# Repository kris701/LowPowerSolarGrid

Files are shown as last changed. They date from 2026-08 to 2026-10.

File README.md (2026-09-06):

# Low Power Solar Grid
A project to make a low power solar setup with a hybrid switcher
The general idea is that most small scale solar chargers and controllers you can buy, takes a lot of base load power.
Say, if you have 300W of solar capacity, its a bit wasteful for the charge controller to be constantly eating 5-10W all day long.

So the general idea is to make a very low power setup that can work with little to no base load.

For this, there are 2 main components, the Low Power Solar Charger and the Low Power Power Switch.
The Charger part adds an extra controller before the charge controller step, which has a Arduino in a low power setup that switches power on and off the 
controller depending on how much light comes in from a light sensor outside. The switches are bistatic relay, so they effectively dont use any base load.
The controller itself uses less than a watt (i cant measure any lower).

The Power Switch part is to have a continuous supply of 12V power to the systems that use it.
It measures the voltage on the battery, and when the voltage is sufficiently high, draws power from the battery. If its too low, it instead draws power
from a 230V to 12V charger.

lpsolargrid



Everything in the 12V range is connected by Anderson connectors to make a unified connector for everything.

Keep in mind that this is a low power setup, so dont expect to draw more than 200-300W from this setup.

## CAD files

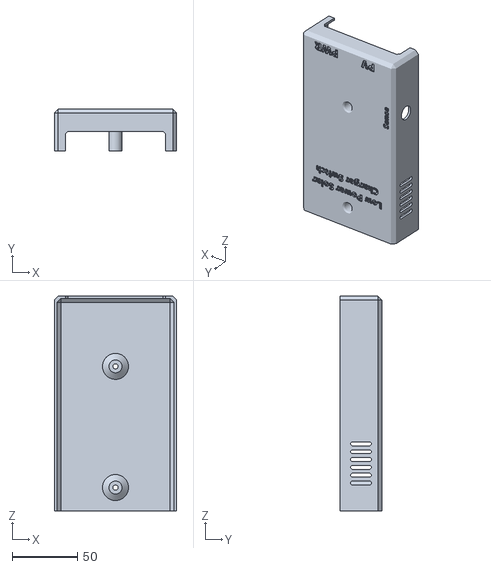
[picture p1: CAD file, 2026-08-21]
3D Prints/SolarSwitch_Cover.stl
94.0 x 32.0 x 165.0

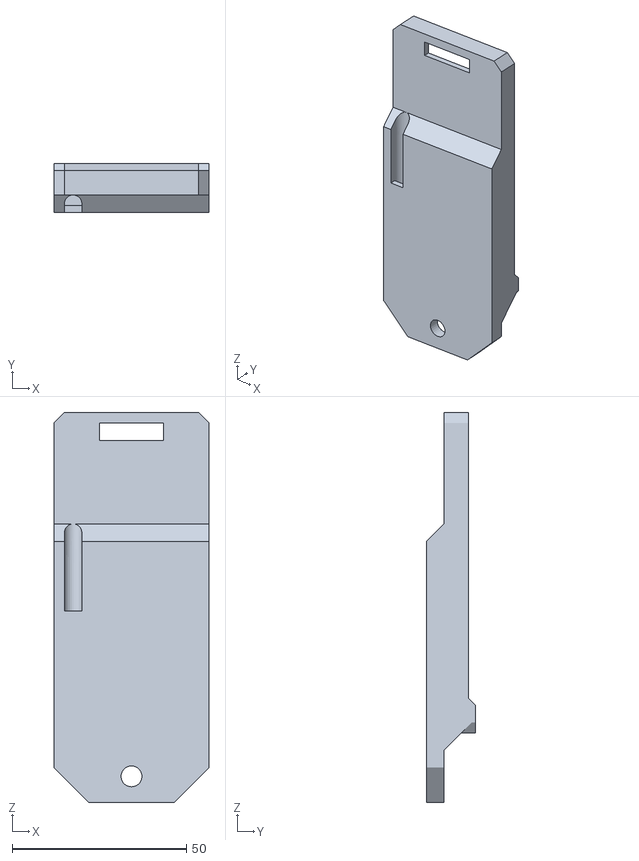
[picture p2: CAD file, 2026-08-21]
3D Prints/SolarSensor_Mount.stl
44.5 x 14.0 x 112.0

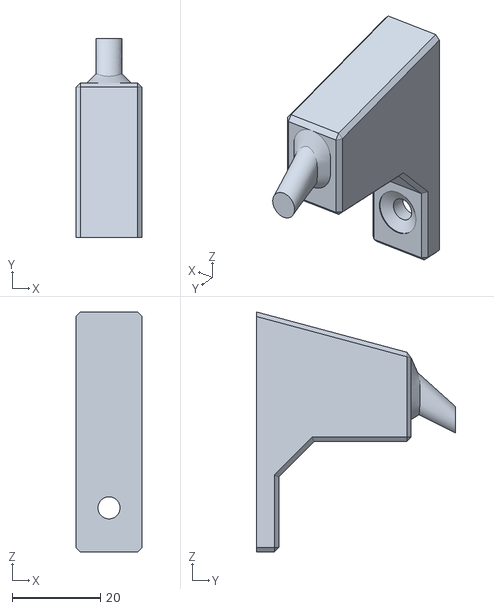
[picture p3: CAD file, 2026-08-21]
3D Prints/SolarPanel_Mount.stl
15.0 x 45.0 x 54.4

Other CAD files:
3D Prints/SolarPanel_Mount.f3d
3D Prints/SolarSensor_Mount.f3d
3D Prints/SolarSwitch_Cover.f3d

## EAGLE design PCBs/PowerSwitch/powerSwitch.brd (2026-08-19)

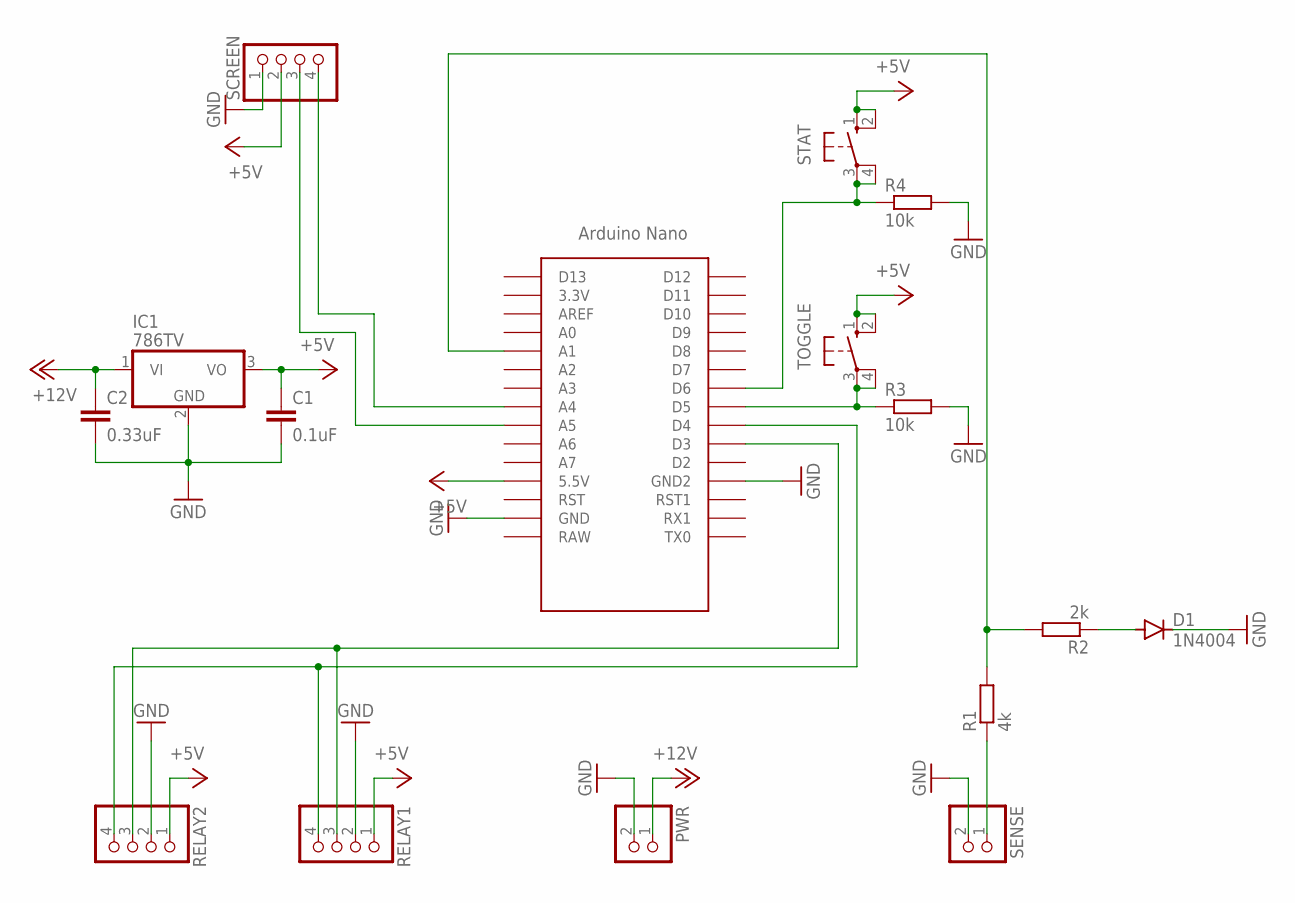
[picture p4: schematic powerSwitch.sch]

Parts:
C1: 0.1uF; C5B2.5
C2: 0.33uF; C5B2.5
D1: 1N4004; DO41-10
IC1: 786TV; TO220V
NANO: NANO
PWR: PINHD-1X2; 1X02
R1: 4k; 0204/7
R2: 2k; 0204/7
R3, R4: 10k; 0204/7
RELAY1, RELAY2: PINHD-1X4; 1X04
SCREEN: PINHD-1X4; 1X04
SENSE: PINHD-1X2; 1X02
STAT: 10-XX; B3F-10XX
TOGGLE: 10-XX; B3F-10XX

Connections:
+5V: C1.1, IC1.3 (VO), NANO.5V (5.5V), RELAY1.1, RELAY2.1, SCREEN.2, STAT.1 (S), STAT.2 (S1), TOGGLE.1 (S), TOGGLE.2 (S1)
+12V: C2.1, IC1.1 (VI), PWR.1
GND: C1.2, C2.2, D1.C, IC1.2 (GND), NANO.GND, NANO.GND1 (GND2), PWR.2, R3.2, R4.2, RELAY1.2, RELAY2.2, SCREEN.1, SENSE.2
unnamed: NANO.D3, RELAY1.3, RELAY2.3
unnamed: NANO.D4, RELAY1.4, RELAY2.4
unnamed: R1.1, SENSE.1
unnamed: NANO.A1, R1.2, R2.2
unnamed: D1.A, R2.1
unnamed: NANO.D5, R3.1, TOGGLE.3, TOGGLE.4 (P1)
unnamed: NANO.D6, R4.1, STAT.3, STAT.4 (P1)
unnamed: NANO.A5, SCREEN.3
unnamed: NANO.A4, SCREEN.4

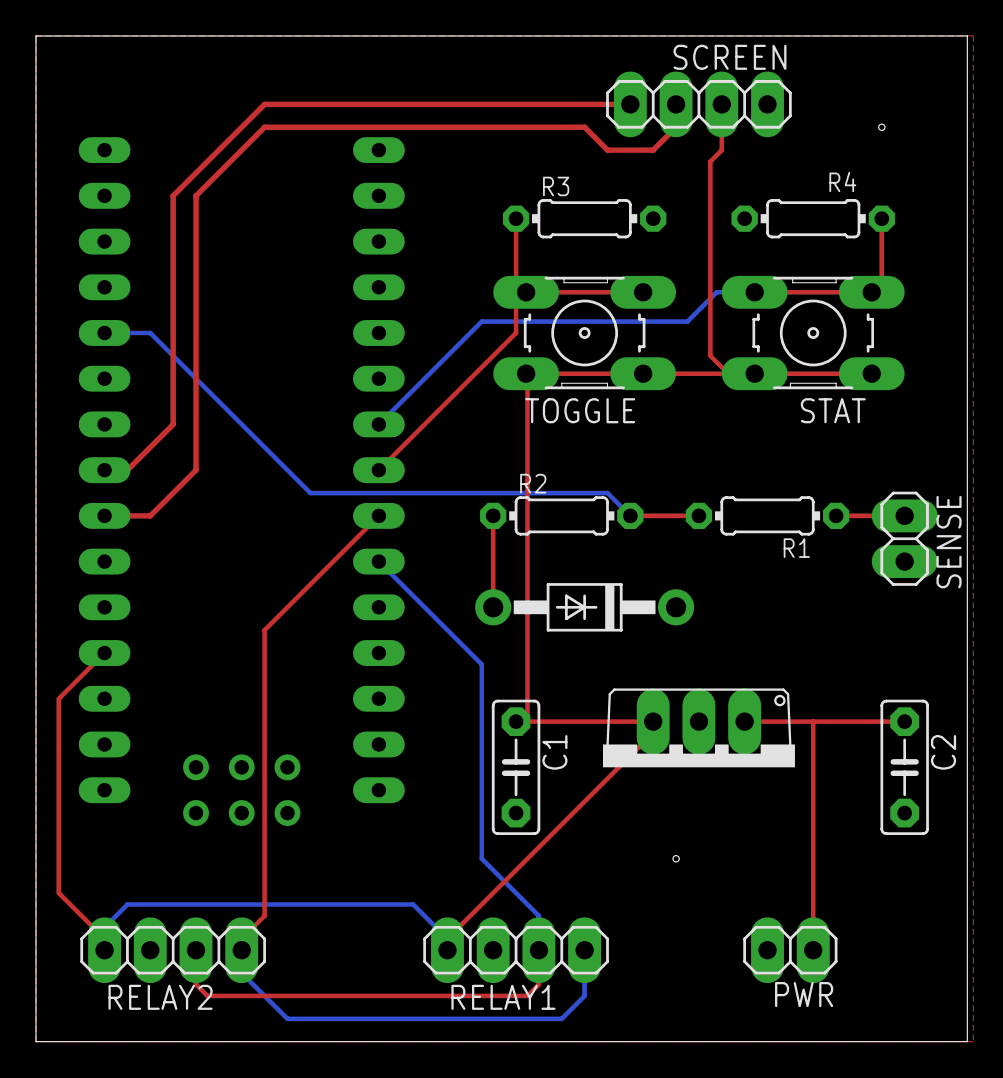
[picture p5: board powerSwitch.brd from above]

Board: 2 copper layers, 51.7 x 55.9 mm, 16 parts (0 on the bottom side), 12 nets.

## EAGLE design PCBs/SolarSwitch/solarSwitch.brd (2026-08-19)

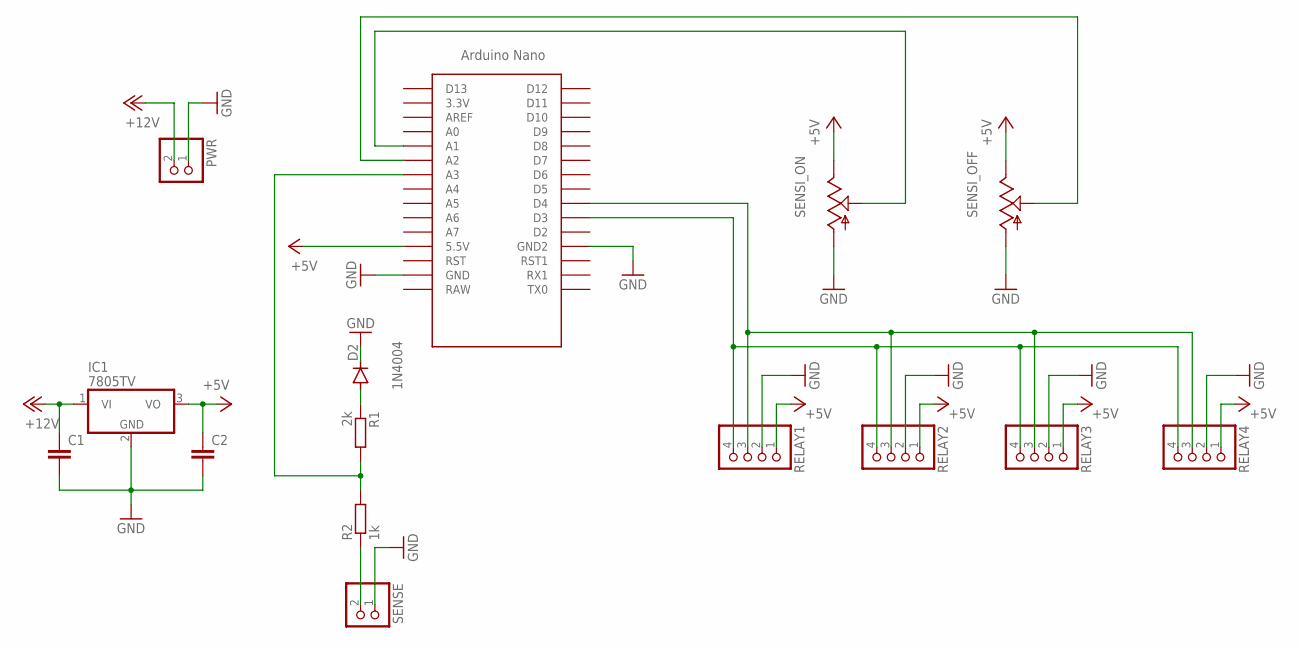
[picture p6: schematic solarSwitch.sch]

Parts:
C1, C2: C5/3; C5B3
D2: 1N4004; DO41-10
IC1: 7805TV; TO220V
PWR: PINHD-1X2; 1X02
R1: 2k; 0204/7
R2: 1k; 0204/7
RELAY1, RELAY2, RELAY3, RELAY4: PINHD-1X4; 1X04
SENSE: PINHD-1X2; 1X02
SENSI_OFF: TRIM_US-B25P; B25P
SENSI_ON: TRIM_US-B25P; B25P
U$1: NANO

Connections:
+5V: C2.1, IC1.3 (VO), RELAY1.1, RELAY2.1, RELAY3.1, RELAY4.1, SENSI_OFF.E, SENSI_ON.E, U$1.5V (5.5V)
+12V: C1.1, IC1.1 (VI), PWR.2
GND: C1.2, C2.2, D2.C, IC1.2 (GND), PWR.1, RELAY1.2, RELAY2.2, RELAY3.2, RELAY4.2, SENSE.1, SENSI_OFF.A, SENSI_ON.A, U$1.GND, U$1.GND1 (GND2)
unnamed: SENSI_ON.S, U$1.A1
unnamed: R2.1, SENSE.2
unnamed: D2.A, R1.1
unnamed: SENSI_OFF.S, U$1.A2
unnamed: RELAY1.3, RELAY2.3, RELAY3.3, RELAY4.3, U$1.D4
unnamed: R1.2, R2.2, U$1.A3
unnamed: RELAY1.4, RELAY2.4, RELAY3.4, RELAY4.4, U$1.D3

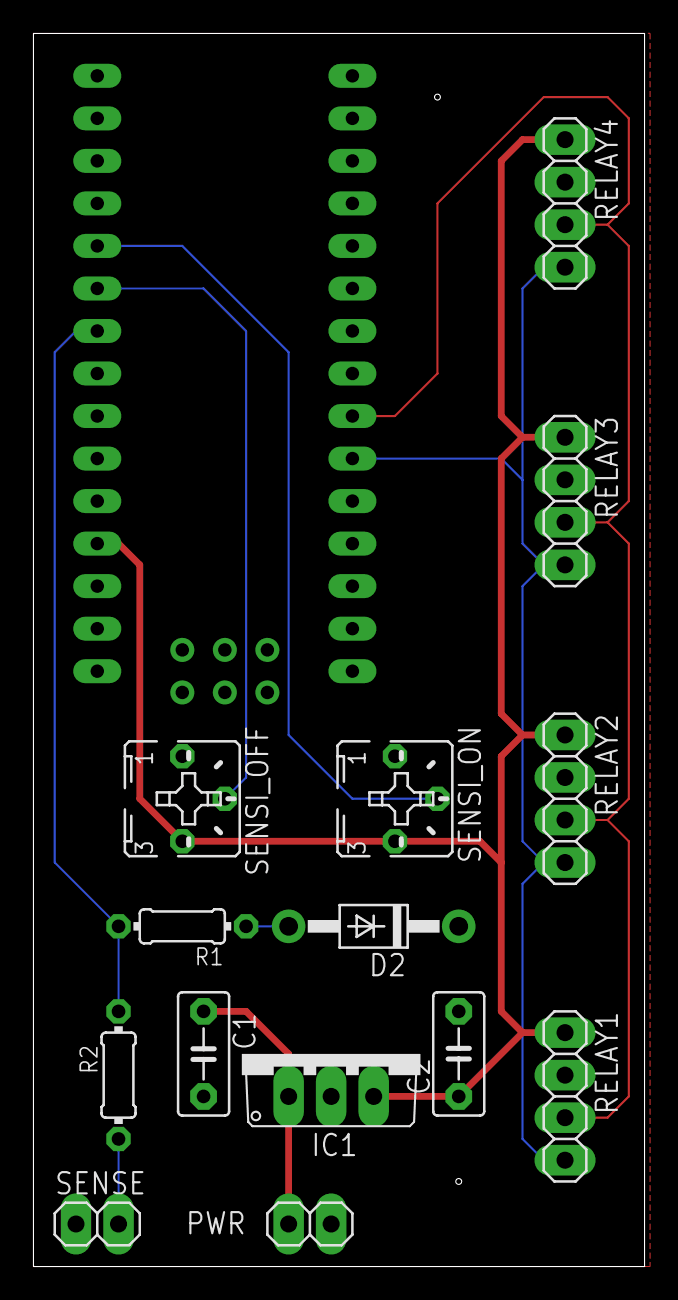
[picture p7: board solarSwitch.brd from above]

Board: 2 copper layers, 36.5 x 73.7 mm, 15 parts (0 on the bottom side), 10 nets.

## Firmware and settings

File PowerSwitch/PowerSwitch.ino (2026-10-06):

#include <EEPROM.h>
#include <SPI.h>
#include <Wire.h>
#include <Adafruit_GFX.h>
#include <Adafruit_SSD1306.h>
#include <LowPower.h>

#define PIN_SENSOR A1

#define PIN_RELAY_SIGNAL 3
#define PIN_RELAY_RESET 4

#define PIN_TOGGLE 5
#define PIN_STAT 6

#define AVERAGE_TIMES 5
#define AVERAGE_DELAY 25

//#define DEBUG

Adafruit_SSD1306 display(128, 32, &Wire, -1);
bool onBattery = false;
bool manuallySet = false;
bool justSwitched = false;
bool showStat = true;

float batTime = 0;
float time = 1;

uint16_t minVoltage = 800;
uint16_t maxVoltage = 920;
uint16_t voltageMap[] = {
	750,
	760,
	770,
	780,
	790,
	800,
	810,
	820,
	830,
	840,
	850,
	860,
	870,
	880,
	890,
	900,
	910,
	920,
	930
};

static const unsigned char PROGMEM logo_battery[] =
{ 0b00000000, 0b00000000,
  0b00000000, 0b00000000,
  0b00000000, 0b00000000,
  0b00000000, 0b00000000,
  0b11111111, 0b11111000,
  0b11111111, 0b11111000,
  0b11111111, 0b11111110,
  0b11111111, 0b11111110,
  0b11111111, 0b11111110,
  0b11111111, 0b11111110,
  0b11111111, 0b11111000,
  0b11111111, 0b11111000,
  0b00000000, 0b00000000,
  0b00000000, 0b00000000,
  0b00000000, 0b00000000,
  0b00000000, 0b00000000 
};

static const unsigned char PROGMEM logo_live[] =
{ 0b00000000, 0b00000000,
  0b00000000, 0b00000000,
  0b00000000, 0b00000000,
  0b00000111, 0b11000000,
  0b00001111, 0b11000000,
  0b00001111, 0b11111000,
  0b11111111, 0b11111000,
  0b11111111, 0b11000000,
  0b11111111, 0b11111000,
  0b00001111, 0b11111000,
  0b00001111, 0b11000000,
  0b00000111, 0b11000000,
  0b00000000, 0b00000000,
  0b00000000, 0b00000000,
  0b00000000, 0b00000000,
  0b00000000, 0b00000000
};

void setup() {
#ifdef DEBUG
	Serial.begin(115200);
	Serial.println("Initializing...!");
#endif
	delay(500);

	if (!display.begin(SSD1306_SWITCHCAPVCC, 0x3C)) {
		Serial.println(F("SSD1306 allocation failed"));
		for (;;);
	}

	display.clearDisplay();
	display.setTextColor(SSD1306_WHITE);
	display.setCursor(25,18);
	display.println(F("Please Wait..."));
	display.setCursor(0, 0);
	display.display();

	int value = EEPROM.read(0);

	pinMode(PIN_TOGGLE, INPUT_PULLUP);
	pinMode(PIN_STAT, INPUT_PULLUP);

	pinMode(PIN_RELAY_SIGNAL, OUTPUT);
	digitalWrite(PIN_RELAY_SIGNAL, 1);
	pinMode(PIN_RELAY_RESET, OUTPUT);
	digitalWrite(PIN_RELAY_RESET, 1);

	if (value == 1) {
		onBattery = true;
		delay(100);
		digitalWrite(PIN_RELAY_SIGNAL, 0);
		delay(100);
		digitalWrite(PIN_RELAY_SIGNAL, 1);
	}
	else {
		onBattery = false;
		delay(100);
		digitalWrite(PIN_RELAY_RESET, 0);
		delay(100);
		digitalWrite(PIN_RELAY_RESET, 1);
	}

#ifdef DEBUG
	Serial.println("System active.");
#endif
	display.clearDisplay();
	display.display();
}

void loop() {
	uint16_t sensorValue = getReadingAvg(PIN_SENSOR);
#ifdef DEBUG
	Serial.print("Sensor: ");
	Serial.println(sensorValue);
#endif

	if (onBattery) {
		if (sensorValue < minVoltage) {
			onBattery = false;
			switchState();
			justSwitched = true;
		}
	}
	else {
		if (sensorValue >= maxVoltage) {
			onBattery = true;
			switchState();
			justSwitched = true;
		}
	}

	if (digitalRead(PIN_TOGGLE)) {
		manuallySet = true;
		onBattery = !onBattery;
		switchState();

		display.clearDisplay();
		display.setCursor(25, 18);
		display.print(F("Set To: "));
		if (onBattery) {
			display.println(F("Bat"));
		}
		else {
			display.println(F("Live"));
		}
		display.display();

		LowPower.idle(SLEEP_4S, ADC_OFF, TIMER2_OFF, TIMER1_OFF, TIMER0_OFF, SPI_OFF, USART0_OFF, TWI_OFF);

		time += 2;
		if (onBattery)
			batTime += 2;

		display.clearDisplay();
		display.display();
	}
	if (digitalRead(PIN_STAT)) {
		showStat = !showStat;
	}

	if (showStat || justSwitched) {
		display.clearDisplay();
		if (onBattery) {
			display.drawBitmap(30, 0, logo_battery,15,15, SSD1306_WHITE);
		}
		else {
			display.drawBitmap(30, 0, logo_live, 15, 15, SSD1306_WHITE);
		}
		display.setCursor(50, 0);
		display.setTextSize(2);
		display.print((String)getBatteryPercent(sensorValue));
		display.println(F("%"));
		display.setTextSize(1);
		display.setCursor(0, 15);

		if (onBattery) {
			if (justSwitched) {
				display.print(F("Live => Bat"));
			}
			else {
				display.print(F("Bat"));
			}
		}
		else {
			if (justSwitched) {
				display.print(F("Bat => Live"));
			}
			else {
				display.print(F("Live"));
			}
		}

		display.print(F(" (Bat "));
		uint8_t percent = (batTime / time) * 100;
		display.print((String)percent);
		display.println(F("%)"));

		display.print(F("Min: "));
		display.print((String)getBatteryPercent(minVoltage));
		display.print(F("%. "));
		display.print(F("Max: "));
		display.print((String)getBatteryPercent(maxVoltage));
		display.println(F("%"));
		display.display();
	}
	else
	{
		display.clearDisplay();
		display.display();
	}

	LowPower.idle(SLEEP_2S, ADC_OFF, TIMER2_OFF, TIMER1_OFF, TIMER0_OFF, SPI_OFF, USART0_OFF, TWI_OFF);

	time++;
	if (onBattery)
		batTime++;

	justSwitched = false;
}

int getReadingAvg(uint16_t pin) {
	uint16_t total = 0;
	for (int i = 0; i < AVERAGE_TIMES; i++) {
		total += analogRead(pin);
		delay(AVERAGE_DELAY);
	}
	return total / AVERAGE_TIMES;
}

void switchState() {
	if (onBattery) {
		digitalWrite(PIN_RELAY_SIGNAL, 0);
		delay(100);
		digitalWrite(PIN_RELAY_SIGNAL, 1);
		EEPROM.write(0, 1);
	}
	else {
		digitalWrite(PIN_RELAY_RESET, 0);
		delay(100);
		digitalWrite(PIN_RELAY_RESET, 1);
		EEPROM.write(0, 0);
	}
}

uint8_t getBatteryPercent(uint16_t voltage) {
	uint8_t total = sizeof(voltageMap) / 2;
	uint8_t index = 0;
	for (uint8_t i = 0; i < total; i++) {
		if (voltageMap[i] > voltage)
			break;
		index = i;
	}
	if (index > total)
		index = total;
	uint8_t percent = ((float)index / ((float)total)) * 100;
#ifdef DEBUG
	Serial.print("Percentage: ");
	Serial.print(percent);
	Serial.print(" index: ");
	Serial.print(index);
	Serial.print(" total: ");
	Serial.println(total);
#endif
	return percent;
}

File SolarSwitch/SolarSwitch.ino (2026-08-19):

#include <LowPower.h>

#define PIN_SENSITIVITY_UP A1
#define PIN_SENSITIVITY_DOWN A2
#define PIN_SENSOR A3

#define PIN_RELAY_SIGNAL 4
#define PIN_RELAY_RESET 3

#define AVERAGE_TIMES 5
#define AVERAGE_DELAY 250

//#define DEBUG

bool isUp = false;

void setup() {
#ifdef DEBUG
	Serial.begin(115200);
	Serial.println("Initializing...!");
#endif
	delay(4000);

	pinMode(PIN_RELAY_SIGNAL, OUTPUT);
	digitalWrite(PIN_RELAY_SIGNAL, 1);
	pinMode(PIN_RELAY_RESET, OUTPUT);
	digitalWrite(PIN_RELAY_RESET, 1);

	delay(100);
	digitalWrite(PIN_RELAY_RESET, 0);
	delay(100);
	digitalWrite(PIN_RELAY_RESET, 1);

	delay(5000);

#ifdef DEBUG
	Serial.println("System active.");
#endif
}

void loop() {
	uint16_t sensorValue = getReadingAvg(PIN_SENSOR);
	uint16_t sensitivityDownValue = getReadingAvg(PIN_SENSITIVITY_DOWN);
	uint16_t sensitivityUpValue = getReadingAvg(PIN_SENSITIVITY_UP);

#ifdef DEBUG
	Serial.print("Up sense: ");
	Serial.print(sensitivityUpValue);
	Serial.print(". Down sense: ");
	Serial.print(sensitivityDownValue);
	Serial.print(". Sense: ");
	Serial.println(sensorValue);
#endif

	if (isUp) {
		if (sensorValue <= sensitivityDownValue) {
#ifdef DEBUG
			Serial.println("Relay off");
#endif
			isUp = false;
			digitalWrite(PIN_RELAY_RESET, 0);
			delay(100);
			digitalWrite(PIN_RELAY_RESET, 1);
		}
	}
	else {
		if (sensorValue >= sensitivityUpValue) {
#ifdef DEBUG
			Serial.println("Relay on");
#endif
			isUp = true;
			digitalWrite(PIN_RELAY_SIGNAL, 0);
			delay(100);
			digitalWrite(PIN_RELAY_SIGNAL, 1);
		}
	}

	LowPower.idle(SLEEP_8S, ADC_OFF, TIMER2_OFF, TIMER1_OFF, TIMER0_OFF, SPI_OFF, USART0_OFF, TWI_OFF);
}

int getReadingAvg(uint16_t pin) {
	uint16_t total = 0;
	for (int i = 0; i < AVERAGE_TIMES; i++) {
		total += analogRead(pin);
		delay(AVERAGE_DELAY);
	}
	return total / AVERAGE_TIMES;
}

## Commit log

2026-08-19 General code setup for the power switch
2026-08-20 Improved power switch code
2026-08-20 Pin flip
2026-08-21 Added 3D printing files
    [SolarPanel_Mount.f3d, SolarPanel_Mount.stl, SolarSensor_Mount.f3d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]
2026-10-06 Saves on-battery time and last toggle state
